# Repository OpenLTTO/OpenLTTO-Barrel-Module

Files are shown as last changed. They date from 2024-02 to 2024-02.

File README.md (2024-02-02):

# OpenLTTO
The OpenLTTO Project is an attempt to recreate the Lazer Tag Team Ops protocol, and game system, in a completely open-source solution. Eventually our intent, is to expand on the LTTO system, adding new functionality, and features, while maintaining backwards compatibility with this classic Lazer Tag gear.

> This Project wouldn't be possible without all the hard work of Richie Mickan https://github.com/rmick
> His work on recreating the LTTO Protocol, and the development of the Combobulator app are core to the firmware and capabilities of this project.

> Additionally this is built on top of the excellent product developed and released by Hasbro/Tiger Electronics. And the work done by Tag Ferret to release the technical specs, and unlock much of the magic of the protocol, and the inner workings.

We intend to do this via a collection of open-source hardware components that can act as building blocks, to build anything you might require for a Lazer Tag game (Taggers, Hosting Pods, Zone controllers, utilities, etc). And an opensource firmware to operate it all. 

Shield: [][cc-by-nc-sa]

This work is licensed under a
[Creative Commons Attribution-NonCommercial-ShareAlike 4.0 International License][cc-by-nc-sa].

[][cc-by-nc-sa]

[cc-by-nc-sa]: http://creativecommons.org/licenses/by-nc-sa/4.0/
[cc-by-nc-sa-image]: https://licensebuttons.net/l/by-nc-sa/4.0/88x31.png
[cc-by-nc-sa-shield]: https://img.shields.io/badge/License-CC%20BY--NC--SA%204.0-lightgrey.svg

# OpenLTTO Barrel Module
The OpenLTTO Barrel Module is designed to mimic the form factor of the LTTO Deluxe blasters "Dual Barrel" Setup, with one optical tube being transmit, and one optical tube for receive. It is designed to easily fit in the end of a 3D Printed optical tube, with a 25mm focusing lens. 

The module includes 5 Pin IR IN and IR OUT ports, as well as an optimized 1A LED Driver for the IR LED, along with paired Muzzle Flash LEDs. The Module supports both outdoor (high power, 1A), and indoor (low power) modes, controlled from the motherboard. And includes a power ballast (capacitor, and inrush arrester pair) to prevent ripples, and ensure smooth operation.

## OpenLTTO Barrel Module Front Side
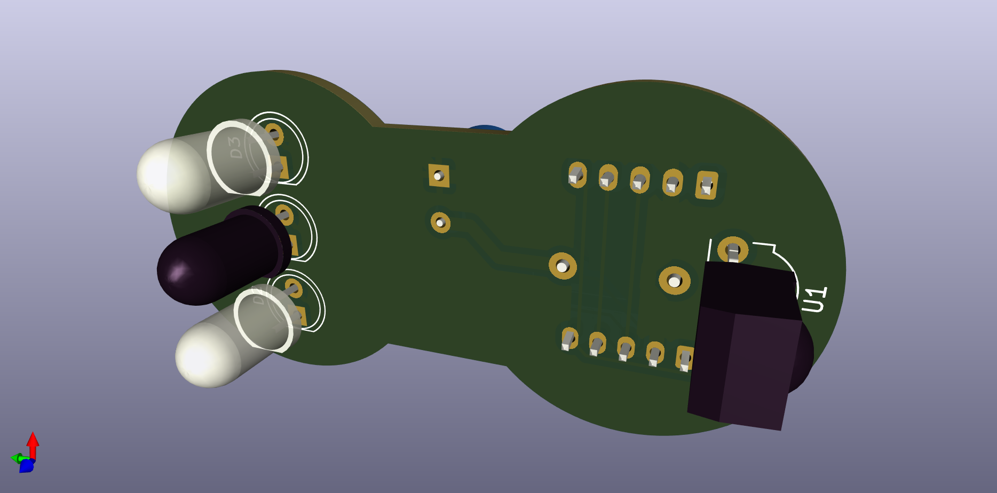
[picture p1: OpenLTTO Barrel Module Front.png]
Image of OpenLTTO Barrel Module Front


## OpenLTTO Barrel Module Back Side
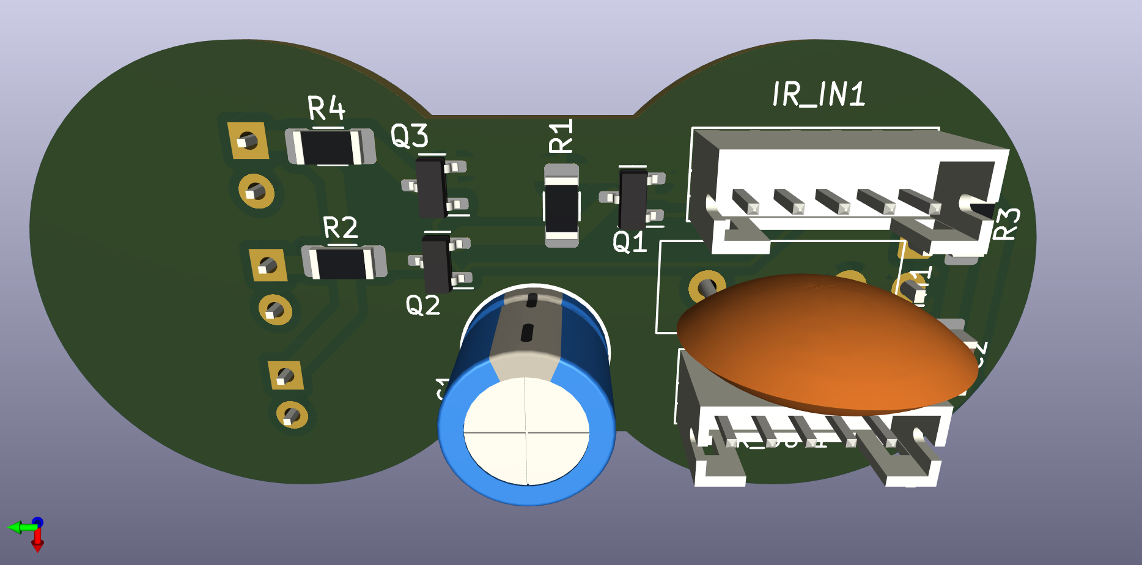
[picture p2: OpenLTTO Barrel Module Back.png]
Image of OpenLTTO Barrel Module Back


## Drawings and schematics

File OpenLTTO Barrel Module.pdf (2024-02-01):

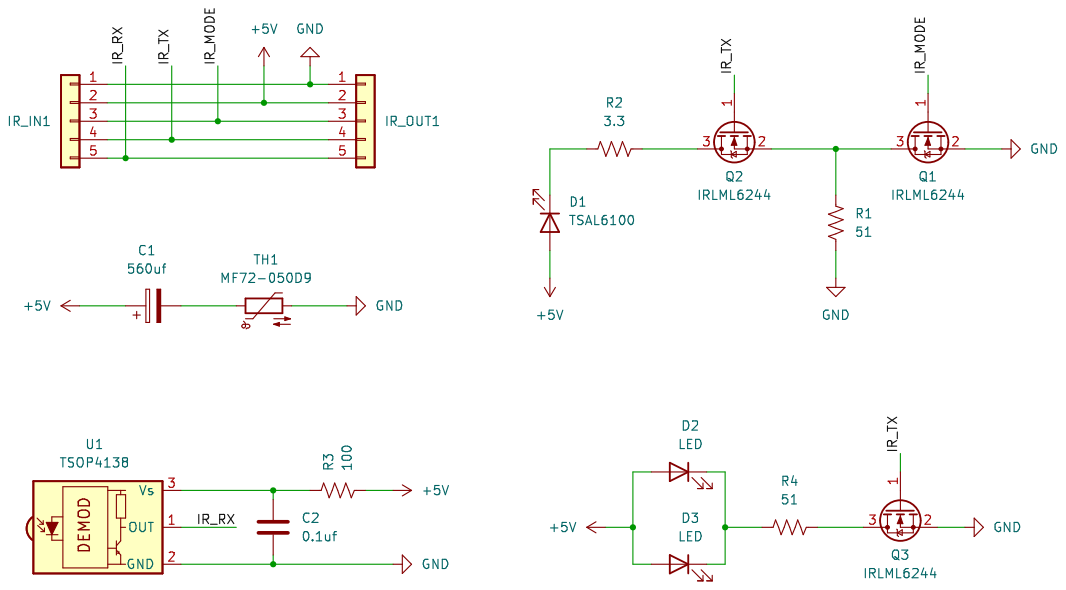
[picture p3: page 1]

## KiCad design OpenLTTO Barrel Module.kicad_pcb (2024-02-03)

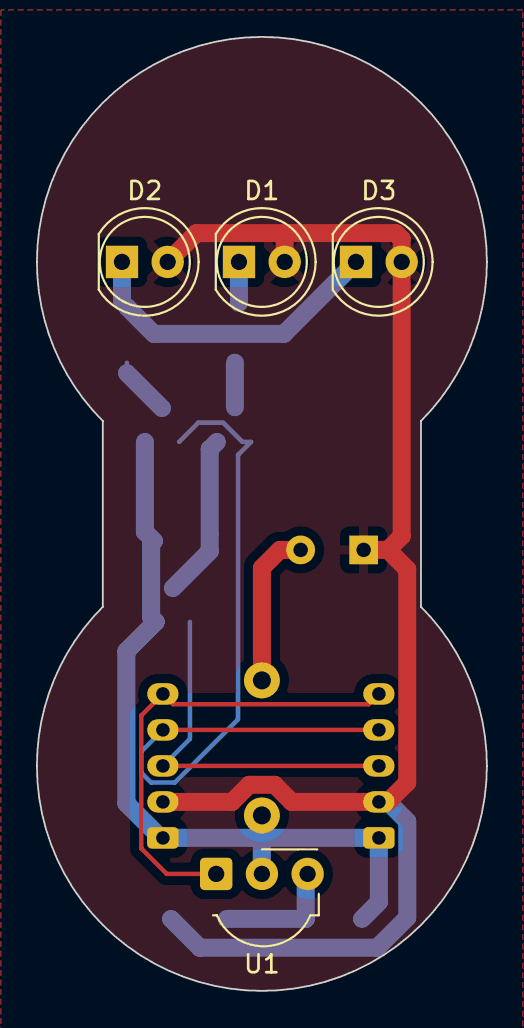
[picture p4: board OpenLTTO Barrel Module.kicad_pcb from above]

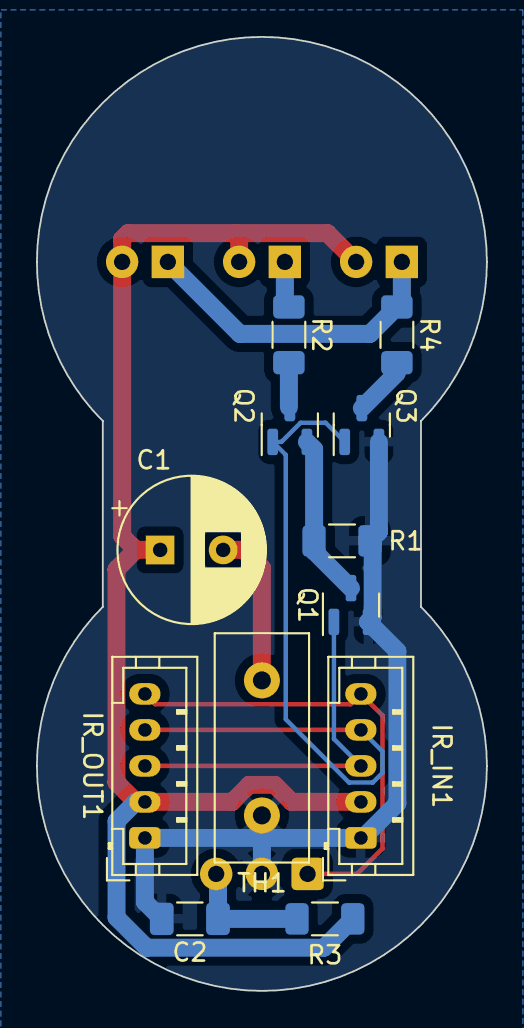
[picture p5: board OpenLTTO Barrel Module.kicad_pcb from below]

Board: 2 copper layers, 25.0 x 53.0 mm, 16 parts (12 on the bottom side), 12 nets.

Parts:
C1: 560uf; CP_Radial_D8.0mm_P3.50mm
C2: 0.1uf; C_1206_3216Metric_Pad1.33x1.80mm_HandSolder
D1: TSAL6100; LED_D5.0mm_IRBlack
D2, D3: LED; LED_D5.0mm_Clear
IR_IN1: JST_PH_B5B-PH-K_1x05_P2.00mm_Vertical
IR_OUT1: JST_PH_B5B-PH-K_1x05_P2.00mm_Vertical
Q1, Q2, Q3: IRLML6244; SOT-23
R1, R4: 51; R_1206_3216Metric_Pad1.30x1.75mm_HandSolder
R2: 3.3; R_1206_3216Metric_Pad1.30x1.75mm_HandSolder
R3: 100; R_1206_3216Metric_Pad1.30x1.75mm_HandSolder
TH1: MF72-050D9; C_Disc_D12.5mm_W5.0mm_P7.50mm
U1: TSOP4138; Vishay_MOLD-3Pin

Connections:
+5V: C1.1, D1.2 (A), D2.2 (A), D3.2 (A), IR_IN1.2, IR_OUT1.2, R3.2
/IR_MODE: IR_IN1.3, IR_OUT1.3, Q1.1 (G)
/IR_RX: IR_IN1.5, IR_OUT1.5, U1.1 (OUT)
/IR_TX: IR_IN1.4, IR_OUT1.4, Q2.1 (G), Q3.1 (G)
GND: C2.2, IR_IN1.1, IR_OUT1.1, Q1.2 (S), Q3.2 (S), R1.2, TH1.2, U1.2 (GND)
unnamed: C1.2, TH1.1
unnamed: D1.1 (K), R2.1
unnamed: D2.1 (K), D3.1 (K), R4.1
unnamed: Q1.3 (D), Q2.2 (S), R1.1
unnamed: Q2.3 (D), R2.2
unnamed: Q3.3 (D), R4.2
unnamed: C2.1, R3.1, U1.3 (Vs)

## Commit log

2024-02-01 Updated schematic metadata, added schematic PDF and renders of PCB
    [OpenLTTO Barrel Module.kicad_sch]
2024-02-02 Updated module to allow 3mm gap between optical elements (for easier assembly design)
    [OpenLTTO Barrel Module.kicad_pcb]
2024-02-03 Minor change, shifted ballast cap to make room for internal baffle on optical assembly
    [OpenLTTO Barrel Module.kicad_pcb]

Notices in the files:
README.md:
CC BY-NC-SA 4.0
